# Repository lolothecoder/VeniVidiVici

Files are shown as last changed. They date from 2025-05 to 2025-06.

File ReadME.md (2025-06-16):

# VeniVidiVici
### Loïc Finette, Oussama Jaffal, Adnane El Haouat
Repository for the Robotics Competition Team “VeniVidiVici”

---

## Overview

This workspace bundles everything needed to get our robot up and running in the competition:

- **ROSArduinoBridge**  
  Low-level firmware running on the Arduino, handling sensor I/O and motor control.

- **diffdrive_arduino**  
  Differential-drive hardware interface for Arduino.

- **rplidar_ros2**  
  Driver for the A1M8 RPLidar unit, published as a ROS 2 node.

- **veni_vidi_vici_bot_one**  
  Template repo integrating SLAM and Nav2—your quick start to mapping and navigation.

---

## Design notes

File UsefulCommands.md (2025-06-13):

run docker image:
docker run -dit --name ros_vvv \
  --privileged \
  --network host \
  --ipc host \
  --device /dev/video0:/dev/video0 \
  --device /dev/ttyUSB0:/dev/ttyUSB0 \
  -e DISPLAY=$DISPLAY \
  -v /tmp/.X11-unix:/tmp/.X11-unix:rw \
  -v /home/triplev/.Xauthority:/root/.Xauthority:ro \
  -v /home/triplev/Documents/VeniVidiVici/veni_vidi_vici_bot_one:/root/ros_ws/src/veni_vidi_vici_bot_one \
  -v /home/triplev/Documents/VeniVidiVici/rplidar_ros2:/root/ros_ws/src/rplidar_ros2 \
  -v /home/triplev/Documents/VeniVidiVici/diffdrive_arduino:/root/ros_ws/src/diffdrive_arduino \
  -v /home/triplev/Documents/VeniVidiVici/ball_tracker:/root/ros_ws/src/ball_tracker \
  -v /dev/bus/usb:/dev/bus/usb \
  leshrimpkiller/vvv:latest bash

execute terminal in same container
docker exec -it ros_vvv bash

build docker image:
docker build -t leshrimpkiller/vvv .

source:
source install/setup.bash

launch robot:
alaunch
ros2 launch veni_vidi_vici_bot_one launch_robot.launch.py 

ros2 launch veni_vidi_vici_bot_one VVV_launch_robot.launch.py activate_loc:=true activate_nav:=true activate_sm:=true

list container:
docker container ls

run teleop:
ateleop
ros2 run teleop_twist_keyboard teleop_twist_keyboard --ros-args -r /cmd_vel:=/diff_cont/cmd_vel_unstamped

Put code on Arduino
acompile ROSArduinoBridge/ && aupload ROSArduinoBridge/

Controlling motors through pyserial
pyserial-miniterm -e /dev/ttyACM0 57600
type: f for battery

create new bash
anewbash
sudo docker exec -it $(sudo docker ps -aqf "ancestor=leshrimpkiller/vvv") bash

Launch lidar
ros2 run rplidar_ros rplidar_composition --ros-args -p serial_port:=/dev/ttyUSB0 -p frame_id:=laser_frame -p angle_compensate:=true -p scan_mode:=Standard

ros2 launch rplidar_ros rplidar.launch.py frame_id:=laser_frame

Run Rviz docker:

ssh -X triplev@172.21.68.240

xhost +local:root  # Allow local root user to access X server

export XAUTHORITY=/home/triplev/.Xauthority

sudo docker run --rm -it --privileged --net=host \
  -e DISPLAY=$DISPLAY \
  -v /tmp/.X11-unix:/tmp/.X11-unix:rw \
  -v /home/triplev/.Xauthority:/root/.Xauthority:ro \
  -v /dev/bus/usb:/dev/bus/usb \
  leshrimpkiller/vvv:latest bash

echo $DISPLAY       
echo $XAUTHORITY 

rviz2

ros2 launch slam_toolbox online_async_launch.py params_file:=./src/veni_vidi_vici_bot_one/config/mapper_params_online_async.yaml use_sim_time:=false

ros2 launch veni_vidi_vici_bot_one VVV_launch_robot.launch.py activate_sm:=true use_ros2_control:=true activate_nav:=true activate_loc:=true

source /opt/ros/humble/setup.bash
source ~/ros_ws/install/setup.bash
export ROS_DOMAIN_ID=5

ros2 launch veni_vidi_vici_bot_one VVV_launch_robot.launch.py activate_nav:=true activate_loc:=true activate_sm:=true use_ros2_control:=true 

ros2 topic pub /start_signal std_msgs/msg/Empty '{}'

 bash -x src/veni_vidi_vici_bot_one/veni_vidi_vici_bot_one/go_bot.sh

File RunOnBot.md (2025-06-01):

Plug in therobot using either an alim or battery

With alim use adapter

With battery take out the adapter and plug in the white JST connector (RED N RED PLEASE). Then plug in the power. Press the reset button on the powerboard. Flip the switch on. If it doesn't work play around with the switch (On and off). MAKE SURE the battery has more than 10.5 V left in it.

Pull new docker image:
docker pull leshrimpkiller/vvv

login info:
ssh: lolon@172.21.69.243
pswd: milotamario64

If you want to use rviz2 or any GUI apps:
ssh -X lolon@172.21.69.243

xhost +local:root  # Allow local root user to access X server

export XAUTHORITY=/home/lolon/.Xauthority

sudo docker run --rm -it --privileged --net=host \
  -e DISPLAY=$DISPLAY \
  -v /tmp/.X11-unix:/tmp/.X11-unix:rw \
  -v /home/lolon/.Xauthority:/root/.Xauthority:ro \
  -v /dev/bus/usb:/dev/bus/usb \
  leshrimpkiller/vvv:latest bash

echo $DISPLAY       
echo $XAUTHORITY 

rviz2 

!!MAKE SURE YOU RUN THE LAUNCH FILE THAT LAUNCHES GUI APPS LAST!!

Open up a bunch of terminals with either 
- anewbash
- docker exec -it <CONTAINER> bash

Source terminal

FIRST run the robot launch file with : 
ros2 launch veni_vidi_vici_bot_one launch_robot.launch.py

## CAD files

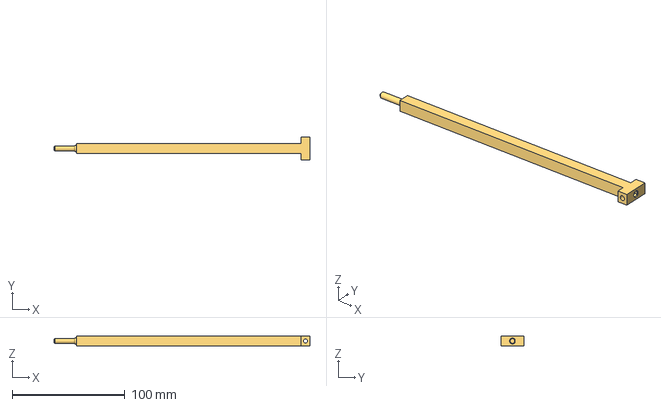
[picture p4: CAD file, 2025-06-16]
CAD/grabber_axe v6 v7.step
227.0 x 20.7 x 8.70 mm

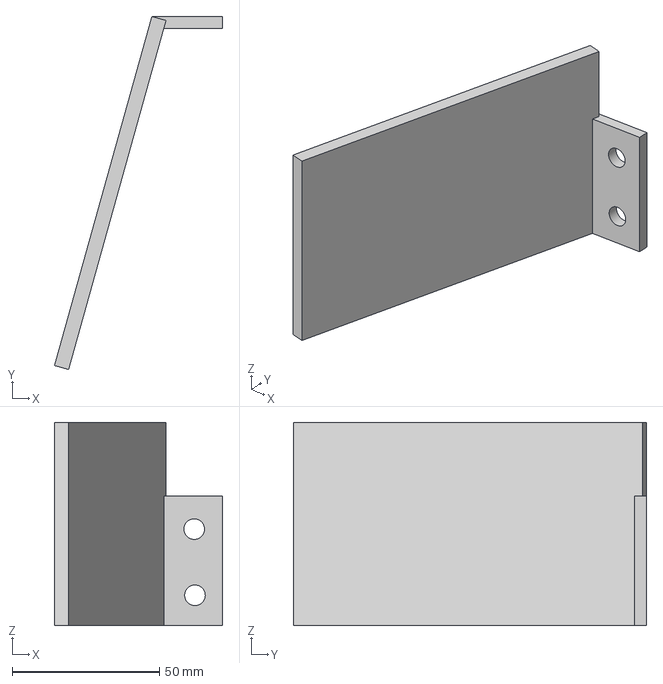
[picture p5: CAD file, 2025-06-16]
CAD/Protege_roue_2 v2.step
57.1 x 119.8 x 69.0 mm

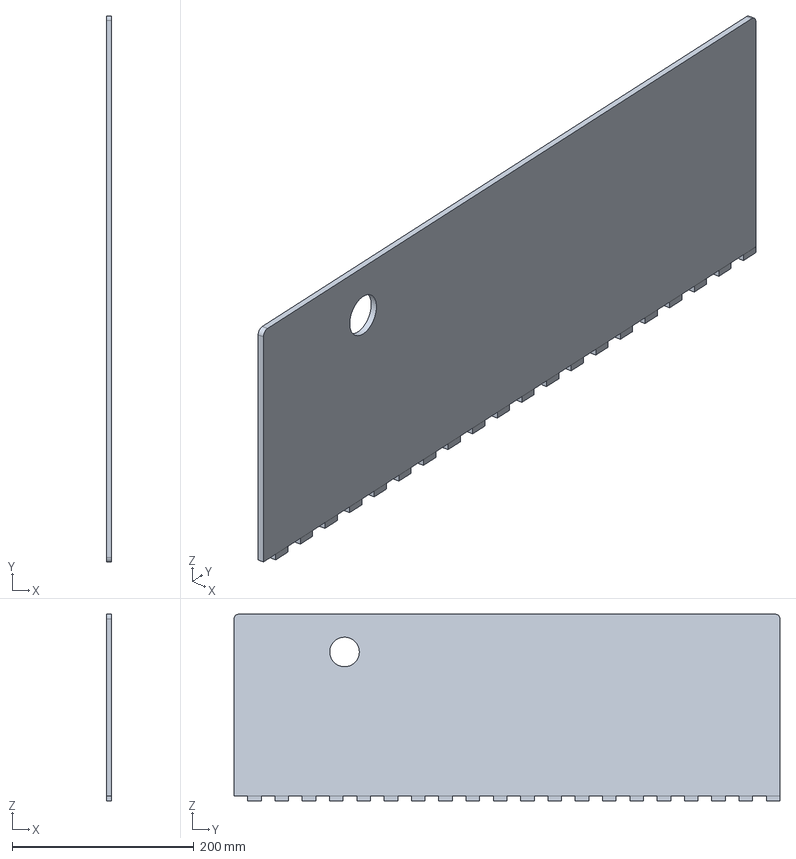
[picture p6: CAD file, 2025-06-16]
CAD/chassis_final_base_lateralll v7.step
5.03 x 600.0 x 205.0 mm

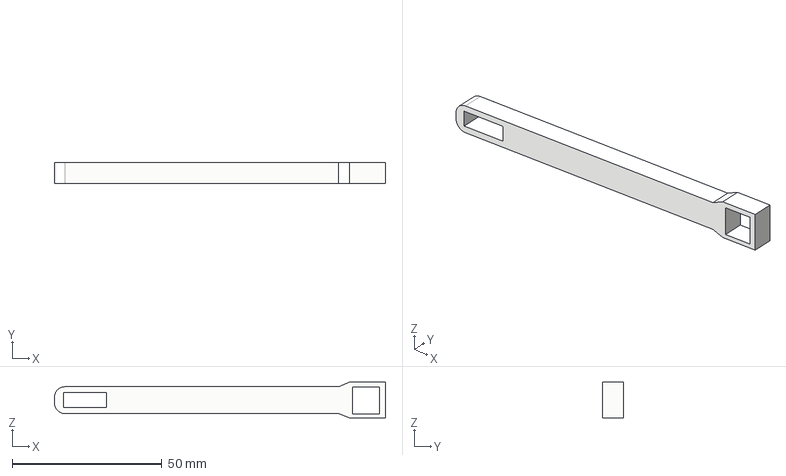
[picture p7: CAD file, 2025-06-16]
CAD/Grab_piece1 v1.step
110.6 x 7.00 x 12.0 mm

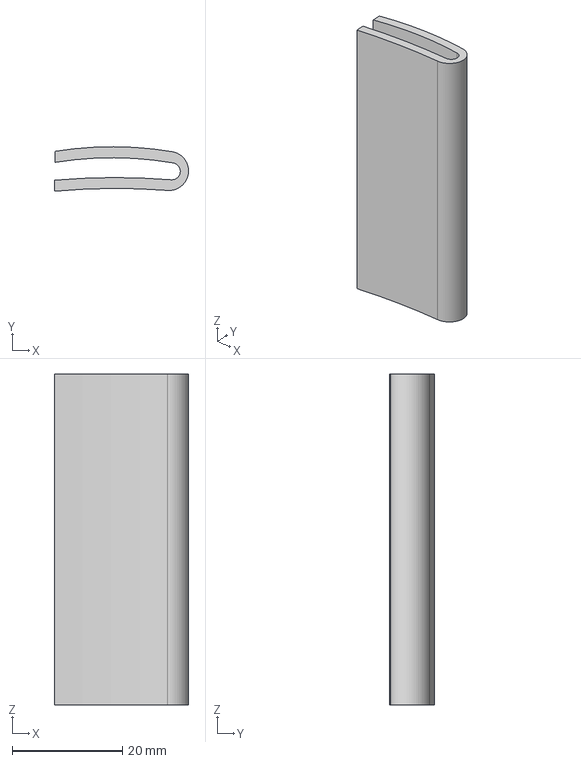
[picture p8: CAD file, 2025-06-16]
CAD/protege_rampe v2.step
24.3 x 8.07 x 60.0 mm

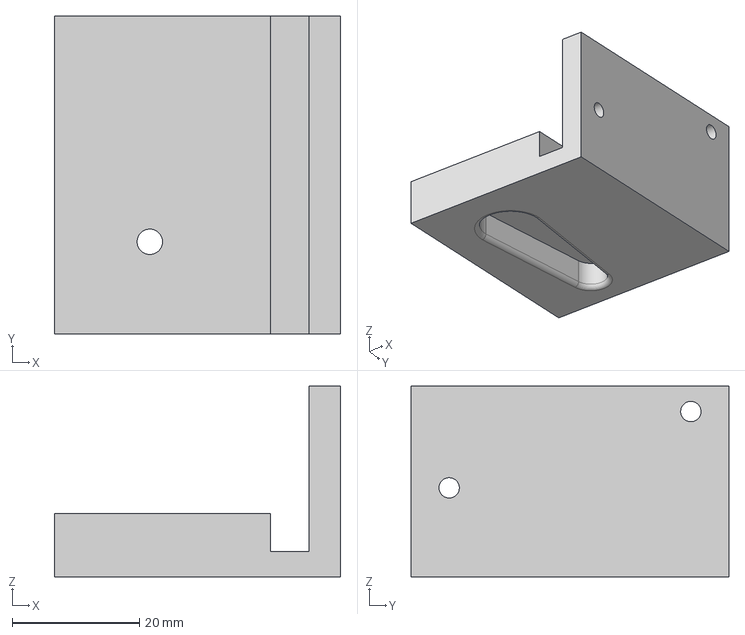
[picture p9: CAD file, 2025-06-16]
CAD/HolderSupport.step
45.0 x 50.0 x 30.0 mm

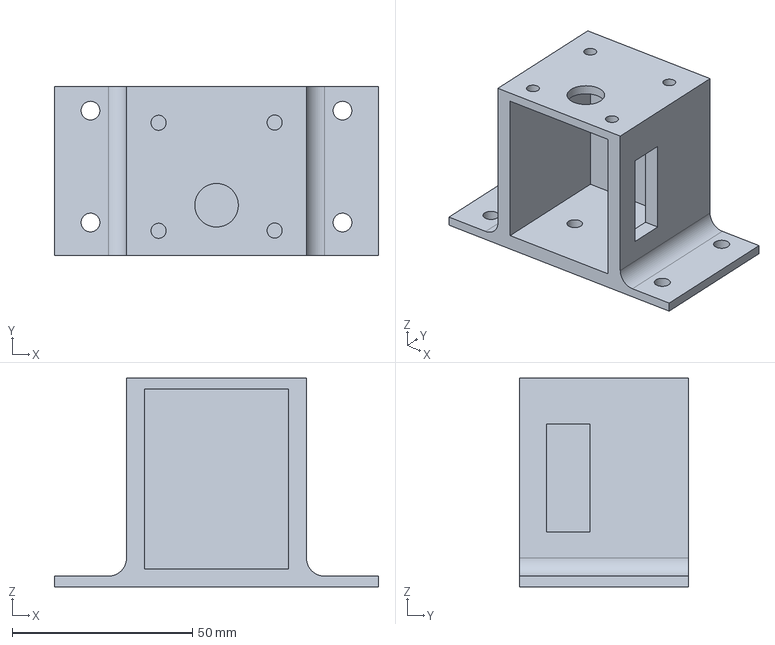
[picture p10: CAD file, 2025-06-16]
CAD/Prototype_final_support_roues v7.step
90.0 x 47.0 x 58.0 mm

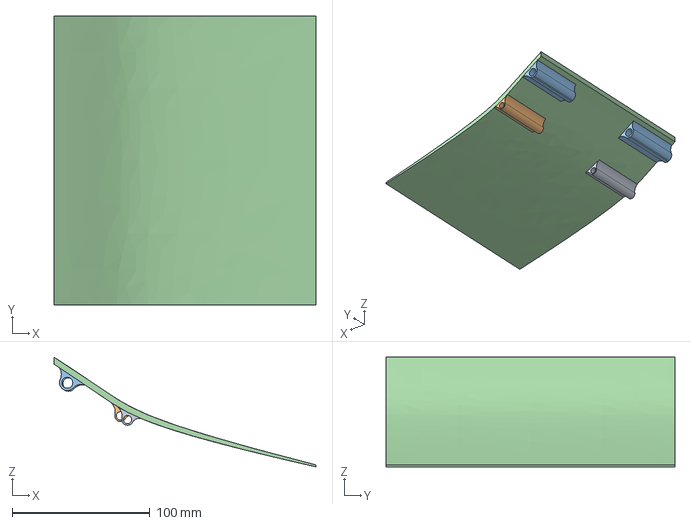
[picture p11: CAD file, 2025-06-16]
CAD/Prototype_final_rampe_du_devant v10.step
190.3 x 210.0 x 79.7 mm

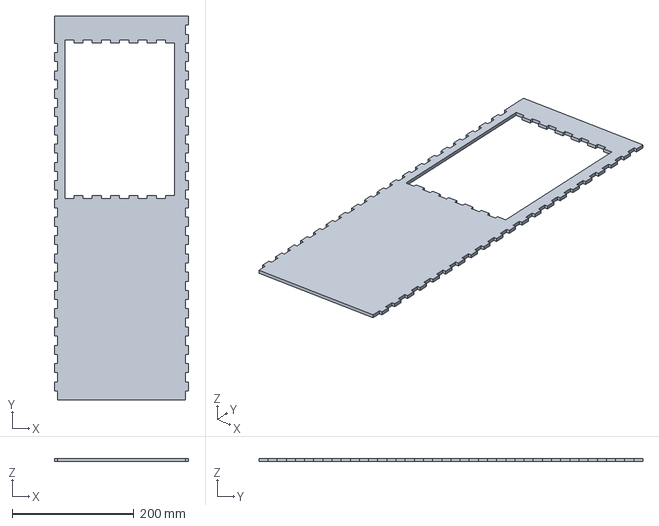
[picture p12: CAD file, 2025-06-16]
CAD/Esquisse_Prototype_Final_Base_du_haut v2.step
220.0 x 629.7 x 5.00 mm

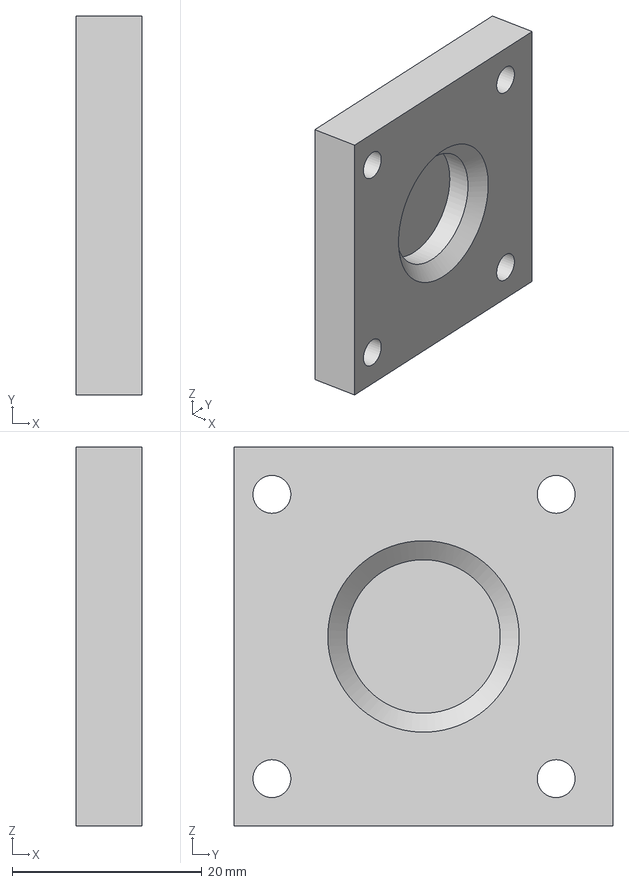
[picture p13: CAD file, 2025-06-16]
CAD/Bearing_Holder.3mf
7.00 x 40.0 x 40.0 mm

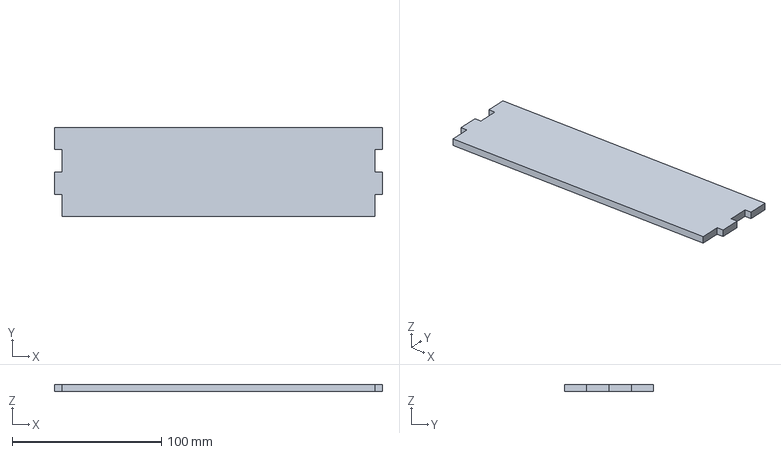
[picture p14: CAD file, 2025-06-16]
CAD/Prototype_finale_pièce_bouton v4.step
220.0 x 60.0 x 5.00 mm

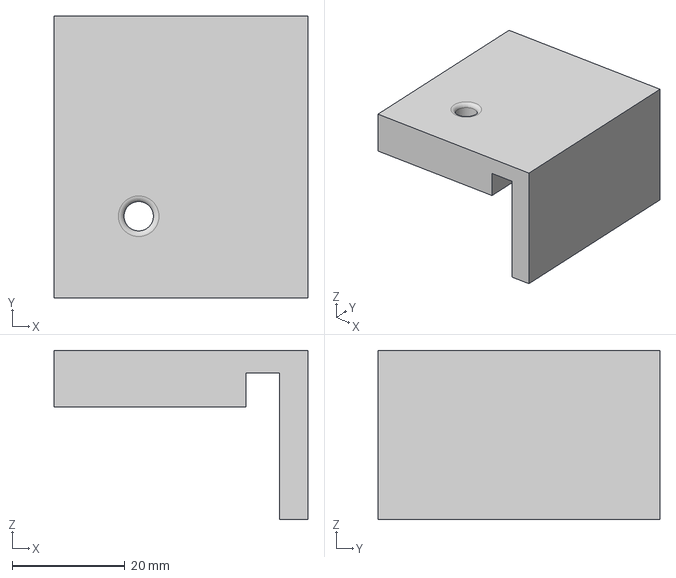
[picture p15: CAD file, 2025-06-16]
CAD/HolderSupportBEARING v3.step
45.0 x 50.0 x 30.0 mm

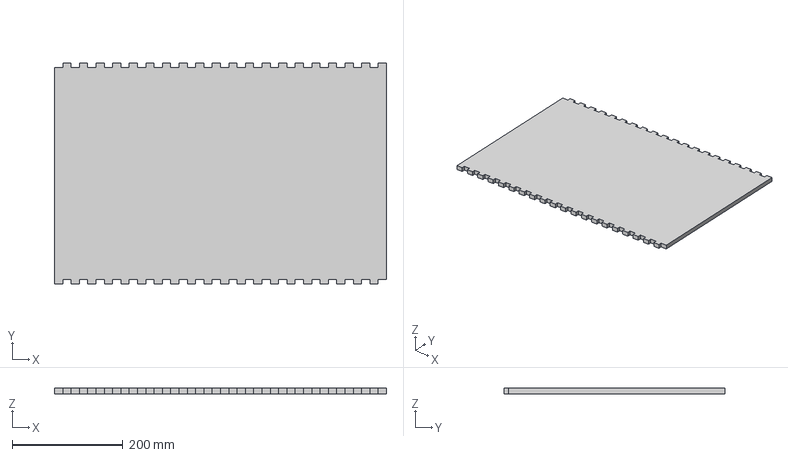
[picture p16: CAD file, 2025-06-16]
CAD/Chassis robot v1.step
600.0 x 400.0 x 10.0 mm

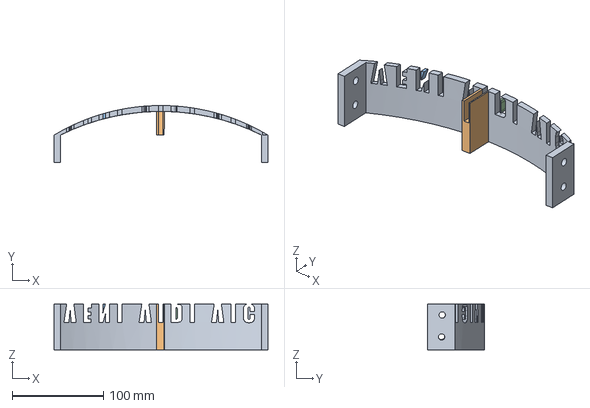
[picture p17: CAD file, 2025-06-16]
CAD/VENI_VIDI_VICI v2.step
235.0 x 62.5 x 50.0 mm

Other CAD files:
CAD/Grab_piece2 v7.step
CAD/Prototype_finale_bearing_support v1.step
CAD/Bearing_holder v1.step

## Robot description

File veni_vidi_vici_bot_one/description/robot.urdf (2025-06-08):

<?xml version="1.0" ?>
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
<robot name="robot">
  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
  <link name="base_link">

    </link>
  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
  <joint name="base_footprint_joint" type="fixed">
    <parent link="base_link"/>
    <child link="base_footprint"/>
    <origin rpy="0 0 0" xyz="0 0 0"/>
  </joint>
  <link name="base_footprint">
    </link>
  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
  <joint name="chassis_joint" type="fixed">
    <parent link="base_link"/>
    <child link="chassis"/>
    <origin xyz="-0.43 0 -0.01"/>
  </joint>
  <link name="chassis">
    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
    <inertial>
      <origin rpy="0 0 0" xyz="0.315 0 0.1025"/>
      <mass value="0.5"/>
      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
    </inertial>
  </link>
  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
  <joint name="left_wheel_joint" type="continuous">
    <parent link="base_link"/>
    <child link="left_wheel"/>
    <origin rpy="-1.5707963267948966 0 0" xyz="0 0.2155 0"/>
    <axis xyz="0 0 1"/>
  </joint>
  <link name="left_wheel">
    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
    <inertial>
      <origin rpy="0 0 0" xyz="0 0 0"/>
      <mass value="0.16"/>
      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
    </inertial>
  </link>
  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
  <joint name="right_wheel_joint" type="continuous">
    <parent link="base_link"/>
    <child link="right_wheel"/>
    <origin rpy="1.5707963267948966 0 0" xyz="0 -0.2155 0"/>
    <axis xyz="0 0 -1"/>
  </joint>
  <link name="right_wheel">
    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
    <inertial>
      <origin rpy="0 0 0" xyz="0 0 0"/>
      <mass value="0.16"/>
      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
    </inertial>
  </link>
  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
  <joint name="right_caster_wheel_joint" type="fixed">
    <parent link="chassis"/>
    <child link="right_caster_wheel"/>
    <origin xyz="0.025 -0.168 -0.024999999999999994"/>
  </joint>
  <link name="right_caster_wheel">
    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
    <inertial>
      <origin rpy="0 0 0" xyz="0 0 0"/>
      <mass value="0.01"/>
      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
    </inertial>
  </link>
  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
  <joint name="left_caster_wheel_joint" type="fixed">
    <parent link="chassis"/>
    <child link="left_caster_wheel"/>
    <origin xyz="0.025 0.168 -0.024999999999999994"/>
  </joint>
  <link name="left_caster_wheel">
    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
    <inertial>
      <origin rpy="0 0 0" xyz="0 0 0"/>
      <mass value="0.01"/>
      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
    </inertial>
  </link>
  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
  <joint name="door_joint" type="continuous">
    <origin rpy="1.57 0 0" xyz="-0.20 0.13 0.13"/>
    <parent link="base_link"/>
    <child link="door_servo_frame"/>
  </joint>
  <link name="door_servo_frame">
    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
    <inertial>
      <mass value="0.04021467988426049"/>
      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
    </inertial>
  </link>
  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
  <joint name="ramp_joint" type="continuous">
    <origin rpy="1.57 0 0" xyz="-0.40 0.13 0.13"/>
    <parent link="base_link"/>
    <child link="ramp_servo_frame"/>
  </joint>
  <link name="ramp_servo_frame">
    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
    <inertial>
      <mass value="0.04021467988426049"/>
      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
    </inertial>
  </link>
  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
  <joint name="collector_joint" type="continuous">
    <origin rpy="1.57 0 0" xyz="0.20 0.13 0.13"/>
    <parent link="base_link"/>
    <child link="collector_servo_frame"/>
  </joint>
  <link name="collector_servo_frame">
    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
    <inertial>
      <mass value="0.04021467988426049"/>
      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
    </inertial>
  </link>
  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
  <ros2_control name="RealRobot" type="system">
    <hardware>
      <plugin>diffdrive_arduino/DiffDriveArduinoHardware</plugin>
      <param name="left_wheel_name">left_wheel_joint</param>
      <param name="right_wheel_name">right_wheel_joint</param>
      <param name="door_servo_name">door_joint</param>
      <param name="ramp_servo_name">ramp_joint</param>
      <param name="collector_servo_name">collector_joint</param>
      <param name="loop_rate">30</param>
      <param name="device">/dev/ttyACM0</param>
      <param name="baud_rate">57600</param>
      <param name="timeout_ms">1000</param>
      <param name="enc_counts_per_rev">3436</param>
      <param name="pid_p">20</param>
      <param name="pid_d">12</param>
      <param name="pid_i">0</param>
      <param name="pid_o">50</param>
    </hardware>
    <joint name="left_wheel_joint">
      <command_interface name="velocity">
        <param name="min">-20</param>
        <param name="max">20</param>
      </command_interface>
      <state_interface name="position"/>
      <state_interface name="velocity"/>
    </joint>
    <joint name="right_wheel_joint">
      <command_interface name="velocity">
        <param name="min">-20</param>
        <param name="max">20</param>
      </command_interface>
      <state_interface name="position"/>
      <state_interface name="velocity"/>
    </joint>
    <joint name="door_joint">
      <command_interface name="velocity">
        <param name="min">-5</param>
        <param name="max">5</param>
      </command_interface>
      <state_interface name="position"/>
      <state_interface name="velocity"/>
    </joint>
    <joint name="ramp_joint">
      <command_interface name="velocity">
        <param name="min">-5</param>
        <param name="max">5</param>
      </command_interface>
      <state_interface name="position"/>
      <state_interface name="velocity"/>
    </joint>
    <joint name="collector_joint">
      <command_interface name="velocity">
        <param name="min">-5</param>
        <param name="max">5</param>
      </command_interface>
      <state_interface name="position"/>
      <state_interface name="velocity"/>
    </joint>
  </ros2_control>
  <joint name="laser_joint" type="fixed">
    <parent link="chassis"/>
    <child link="laser_frame"/>
    <origin rpy="0 0 0" xyz="0.445 0.04 0.28"/>
  </joint>
  <link name="laser_frame">
    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
    <inertial>
      <origin rpy="0 0 0" xyz="0 0 0"/>
      <mass value="0.1"/>
      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
    </inertial>
  </link>
  <joint name="camera_joint" type="fixed">
    <parent link="chassis"/>
    <child link="camera_link"/>
    <origin rpy="0 0.436332 0" xyz="0.615 0 0.24"/>
  </joint>
  <link name="camera_link">
    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
  </link>
  <joint name="camera_optical_joint" type="fixed">
    <parent link="camera_link"/>
    <child link="camera_link_optical"/>
    <origin rpy="-1.5707963267948966 0 -1.5707963267948966" xyz="0 0 0"/>
  </joint>
  <link name="camera_link_optical"/>
</robot>

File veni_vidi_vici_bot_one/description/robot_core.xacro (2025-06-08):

<?xml version="1.0"?>
<robot xmlns:xacro="http://www.ros.org/wiki/xacro" >

    <xacro:include filename="inertial_macros.xacro"/>


    <xacro:property name="chassis_length" value="0.63"/>
    <xacro:property name="chassis_width" value="0.35"/>
    <xacro:property name="chassis_height" value="0.205"/>
    <xacro:property name="chassis_mass" value="4.75"/>
    <xacro:property name="wheel_radius" value="0.06"/>
    <xacro:property name="wheel_thickness" value="0.061"/>
    <xacro:property name="wheel_mass" value="0.160"/>
    <xacro:property name="wheel_offset_x" value="0.43"/>
    <xacro:property name="wheel_offset_y" value="0.185"/>
    <xacro:property name="wheel_offset_z" value="0.01"/>
    <xacro:property name="caster_wheel_radius" value="0.025"/>
    <xacro:property name="caster_wheel_mass" value="0.01"/>
    <xacro:property name="caster_wheel_offset_x" value="0.025"/>
    <xacro:property name="caster_wheel_offset_y" value="0.168"/>
    <xacro:property name="caster_wheel_offset_z" value="${wheel_offset_z - wheel_radius + caster_wheel_radius}"/>

    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

    <link name="base_link">

    </link>

    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

    <joint name="base_footprint_joint" type="fixed">
        <parent link="base_link"/>
        <child link="base_footprint"/>
        <origin xyz="0 0 0" rpy="0 0 0"/>
    </joint>

    <link name="base_footprint">
    </link>


    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

    <joint name="chassis_joint" type="fixed">
        <parent link="base_link"/>
        <child link="chassis"/>
        <origin xyz="${-wheel_offset_x} 0 ${-wheel_offset_z}"/>
    </joint>

    <link name="chassis">
        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
        <xacro:inertial_box mass="0.5" x="${chassis_length}" y="${chassis_width}" z="${chassis_height}">
            <origin xyz="${chassis_length/2} 0 ${chassis_height/2}" rpy="0 0 0"/>
        </xacro:inertial_box>
    </link>

    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

    <joint name="left_wheel_joint" type="continuous">
        <parent link="base_link"/>
        <child link="left_wheel"/>
        <origin xyz="0 ${wheel_offset_y + wheel_thickness/2} 0" rpy="-${pi/2} 0 0" />
        <axis xyz="0 0 1"/>
    </joint>

    <link name="left_wheel">
        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
        <xacro:inertial_cylinder mass="${wheel_mass}" length="${wheel_thickness}" radius="${wheel_radius}">
            <origin xyz="0 0 0" rpy="0 0 0"/>
        </xacro:inertial_cylinder>
    </link>

    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

    <joint name="right_wheel_joint" type="continuous">
        <parent link="base_link"/>
        <child link="right_wheel"/>
        <origin xyz="0 ${-(wheel_offset_y + wheel_thickness/2)} 0" rpy="${pi/2} 0 0" />
        <axis xyz="0 0 -1"/>
    </joint>

    <link name="right_wheel">
        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
        <xacro:inertial_cylinder mass="${wheel_mass}" length="${wheel_thickness}" radius="${wheel_radius}">
            <origin xyz="0 0 0" rpy="0 0 0"/>
        </xacro:inertial_cylinder>
    </link>

    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

    <joint name="right_caster_wheel_joint" type="fixed">
        <parent link="chassis"/>
        <child link="right_caster_wheel"/>
        <origin xyz="${caster_wheel_offset_x} ${-caster_wheel_offset_y} ${caster_wheel_offset_z}"/>
    </joint>


    <link name="right_caster_wheel">
        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
        <xacro:inertial_sphere mass="${caster_wheel_mass}" radius="${caster_wheel_radius}">
            <origin xyz="0 0 0" rpy="0 0 0"/>
        </xacro:inertial_sphere>
    </link>


    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

    <joint name="left_caster_wheel_joint" type="fixed">
        <parent link="chassis"/>
        <child link="left_caster_wheel"/>
        <origin xyz="${caster_wheel_offset_x} ${caster_wheel_offset_y} ${caster_wheel_offset_z}"/>
    </joint>


    <link name="left_caster_wheel">
        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
        <xacro:inertial_sphere mass="${caster_wheel_mass}" radius="${caster_wheel_radius}">
            <origin xyz="0 0 0" rpy="0 0 0"/>
        </xacro:inertial_sphere>
    </link>

    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

    <joint name="door_joint" type="continuous">
        <origin xyz="-0.20 0.13 0.13" rpy="1.57 0 0"/>
        <parent link="base_link"/>
        <child link="door_servo_frame"/>
    </joint>

    <link name="door_servo_frame">
        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
        <inertial>
            <mass value="0.04021467988426049"/>
            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
        </inertial>
    </link>

    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

    <joint name="ramp_joint" type="continuous">
        <origin xyz="-0.40 0.13 0.13" rpy="1.57 0 0"/>
        <parent link="base_link"/>
        <child link="ramp_servo_frame"/>
    </joint>

    <link name="ramp_servo_frame">
        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
        <inertial>
            <mass value="0.04021467988426049"/>
            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
        </inertial>
    </link>

    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

    <joint name="collector_joint" type="continuous">
        <origin xyz="0.20 0.13 0.13" rpy="1.57 0 0"/>
        <parent link="base_link"/>
        <child link="collector_servo_frame"/>
    </joint>

    <link name="collector_servo_frame">
        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
        <inertial>
            <mass value="0.04021467988426049"/>
            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
        </inertial>
    </link>

    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

    <joint name="imu_joint" type="fixed">
        <origin xyz="-0.16 0.05 0.20" rpy="0 0 0"/>
        <parent link="base_link"/>
        <child link="imu_link"/>
    </joint>

    <link name="imu_link">
        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
        <inertial>
            <mass value="0.04021467988426049"/>
            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
        </inertial>
    </link>

</robot>

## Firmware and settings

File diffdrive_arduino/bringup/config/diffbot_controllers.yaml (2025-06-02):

controller_manager:
  ros__parameters:
    update_rate: 10  # Hz

    joint_state_broadcaster:
      type: joint_state_broadcaster/JointStateBroadcaster

    diffbot_base_controller:
      type: diff_drive_controller/DiffDriveController

diffbot_base_controller:
  ros__parameters:
    left_wheel_names: ["left_wheel_joint"]
    right_wheel_names: ["right_wheel_joint"]

    wheel_separation: 0.44
    #wheels_per_side: 1  # actually 2, but both are controlled by 1 signal
    wheel_radius: 0.06

    wheel_separation_multiplier: 1.0
    left_wheel_radius_multiplier: 1.0
    right_wheel_radius_multiplier: 1.0

    publish_rate: 50.0
    odom_frame_id: odom
    base_frame_id: base_link
    pose_covariance_diagonal : [0.001, 0.001, 0.001, 0.001, 0.001, 0.01]
    twist_covariance_diagonal: [0.001, 0.001, 0.001, 0.001, 0.001, 0.01]

    open_loop: true
    enable_odom_tf: true

    cmd_vel_timeout: 0.5
    #publish_limited_velocity: true
    use_stamped_vel: false
    #velocity_rolling_window_size: 10

    # Velocity and acceleration limits
    # Whenever a min_* is unspecified, default to -max_*
    linear.x.has_velocity_limits: true
    linear.x.has_acceleration_limits: true
    linear.x.has_jerk_limits: false
    linear.x.max_velocity: 1.0
    linear.x.min_velocity: -1.0
    linear.x.max_acceleration: 1.0
    linear.x.max_jerk: 0.0
    linear.x.min_jerk: 0.0

    angular.z.has_velocity_limits: true
    angular.z.has_acceleration_limits: true
    angular.z.has_jerk_limits: false
    angular.z.max_velocity: 1.0
    angular.z.min_velocity: -1.0
    angular.z.max_acceleration: 1.0
    angular.z.min_acceleration: -1.0
    angular.z.max_jerk: 0.0
    angular.z.min_jerk: 0.0

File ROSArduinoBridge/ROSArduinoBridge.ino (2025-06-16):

#include <Servo.h>
#include <Adafruit_MPU6050.h>
#include <Adafruit_Sensor.h>
#include <Wire.h>
/*********************************************************************
 *  ROSArduinoBridge
 *  ...
 *********************************************************************/

#define USE_BASE      // Enable the base controller code

#ifdef USE_BASE
   #define ARDUINO_ENC_COUNTER
   #define ESCON_MAXON
   #define GRABBER
   #define BATTERY
   #define CUSTOM_SERVOS
   //Adafruit_MPU6050 mpu;
   #define SPIN_BACK  2000
#endif

#undef USE_SERVOS     // Disable use of PWM servos

#define BAUDRATE       57600
#define MAX_PWM        255

#if defined(ARDUINO) && ARDUINO >= 100
  #include "Arduino.h"
#else
  #include "WProgram.h"
#endif

#include "commands.h"
#include "sensors.h"
#include "sensors_updated.h"

#ifdef USE_SERVOS
  #include <Servo.h>
  #include "servos.h"
#endif

#ifdef USE_BASE
  #include <Servo.h>
  #include "custom_servos.h"
  #include "motor_driver.h"
  #include "encoder_driver.h"
  #include "diff_controller.h"

  #define PID_RATE           30     // Hz
  const int PID_INTERVAL = 1000 / PID_RATE;
  unsigned long nextPID = PID_INTERVAL;

  #define AUTO_STOP_INTERVAL 2000
  long lastMotorCommand   = AUTO_STOP_INTERVAL;
  long lastGrabberCommand = AUTO_STOP_INTERVAL;
  long lastServoCommand   = AUTO_STOP_INTERVAL;
#endif

/* Globals for serial parsing */
int arg = 0;
int index = 0;
char chr;
char cmd;
char argv1[16];
char argv2[16];
long arg1;
long arg2;
bool collector_activated = false;
float left_speed = 0;
float right_speed = 0;
float voltage_battery = 0;
float a_x = 0; float a_y = 0; float a_z = 0;
float g_x = 0; float g_y = 0; float g_z = 0;

const int encoderPinA = A0;
unsigned long switchCount = 0;
bool lastA = LOW;
unsigned long lastReport = 0;
bool grabber = false;
bool stuck = false;
unsigned long stuckTime = 0;
unsigned long checkEncoder = 0;
bool set_time = false;

void battery_level(){
        float value = analogRead(BATTERY_PIN);
        float pin_volt = value / MAX_ARD_VAL * MAX_PIN_VAL;
        float true_bat_volt = pin_volt * (R7 + R8) / R8;
        //Serial.println("Battery Voltage:");
        //Serial.println(true_bat_volt);
        voltage_battery = true_bat_volt;  // Store for later use
    }

/* Encoder/stuck‐detection specifics */
#ifdef USE_BASE
  // We’ll poll A0 as a digital input for the grabber encoder
  #define ENCODER_A_PIN         A0

  volatile unsigned long pulseCount         = 0;    // counts BOTH edges on A0
  uint8_t                lastA0state        = LOW;

  const unsigned long    CHECK_WINDOW       = 500UL;   // 500 ms window
  const unsigned int     MIN_PULSES         = 30;      // ≥30 edges per window ⇒ “turning”
  const unsigned long    REVERSE_DURATION   = 2000UL;  // 2 seconds to reverse when stuck

  unsigned long          lastWindowTime       = 0;
  unsigned long          lastWindowPulseCount = 0;
  unsigned long          reverseUntil         = 0;     // millis until which we reverse
  bool                   currentlyReversing   = false;

  // Default grabber speed (PWM). Adjust as needed.
  const int              DEFAULT_GRABBER_SPEED = 100;
#endif

/* Forward declarations */
void resetCommand();
int runCommand();
void setGrabberSpeed(int spd);

/* Clear the current command parameters */
void resetCommand() {
  cmd = NULL;
  memset(argv1, 0, sizeof(argv1));
  memset(argv2, 0, sizeof(argv2));
  arg1 = 0;
  arg2 = 0;
  arg = 0;
  index = 0;
}

/* Run a command. Commands are defined in commands.h */
int runCommand() {
  int i = 0;
  char *p = argv1;
  char *str;
  int pid_args[4];
  arg1 = atoi(argv1);
  arg2 = atoi(argv2);

  switch(cmd) {

#ifdef USE_BASE
    case READ_ENCODERS:
      Serial.print(readEncoder(LEFT));
      Serial.print(" ");
      Serial.println(readEncoder(RIGHT));
      break;
    case MOTOR_RAW_PWM:
      lastMotorCommand = millis();
      resetPID();
      moving = 0; // temporarily disable PID
      setMotorSpeeds(arg1, arg2);
      left_speed  = arg1;
      right_speed = arg2;
      //if (stuck){
      //  setGrabberSpeed(80);
      //}
      Serial.println("OK");
      break;
    case GRABBER_RAW_PWM:
      lastGrabberCommand = millis();
      if(arg1!= 0){
        collector_activated = true;
        checkEncoder = millis();
      }
      if(stuck){
        if(millis() - stuckTime > SPIN_BACK){
          stuck = false;
          collector_activated = false;
          //Serial.println("UNSTUCK");
        }
        setGrabberSpeed(-arg1);
      }
      else{
        setGrabberSpeed(arg1);
      }

      if(arg1 == 0) {
        collector_activated = false;
        currentlyReversing  = false;
        reverseUntil        = 0;
        grabber = false;
        stuck = false;
        set_time = false;
      }
      Serial.println("OK");
      break;
    case BATTERY_LEVEL:
      battery_level();
      Serial.print("Battery Voltage: ");
      Serial.println(voltage_battery);
      Serial.println("OK");
      break;
    case ACTIVATE_SERVO:
      lastServoCommand = millis();
      setServo(arg1, arg2);
      Serial.println("OK");
      break;
    case GET_INFO:
      Serial.print(left_speed);
      Serial.print(" ");
      Serial.println(right_speed);
      break;
    case GET_IMU:
      //Serial.print(a_x);
      //Serial.print(" ");
      //Serial.print(a_y);
      //Serial.print(" ");
      //Serial.print(a_z);
      //Serial.print(" ");
      //Serial.print(g_x);
      //Serial.print(" ");
      //Serial.print(g_y);
      //Serial.print(" ");
      //Serial.println(g_z);
      break;
#endif

    default:
      Serial.println("Invalid Command");
      break;
  }
  return 0;
}

/* Setup function—runs once at startup. */
void setup() {
  Serial.begin(BAUDRATE);
  //Wire.begin();                    //  ← Initialize I²C bus
  //if (! mpu.begin()) {             //  ← Probe the sensor
  //  Serial.println("Failed to find MPU6050!");
  //  while (1) delay(10);
  //}
  pinMode(LEFT_ENABLE, OUTPUT);
  pinMode(LEFT_PWM, OUTPUT);
  pinMode(LEFT_DIRECTION, OUTPUT);

  pinMode(RIGHT_ENABLE, OUTPUT);
  pinMode(RIGHT_PWM, OUTPUT);
  pinMode(RIGHT_DIRECTION, OUTPUT);

  pinMode(GRABBER_DIRECTION, OUTPUT);
  pinMode(GRABBER_PWM, OUTPUT);

  pinMode(BATTERY_PIN, INPUT);
  pinMode(encoderPinA, INPUT_PULLUP);
  lastA = digitalRead(encoderPinA);
  //mpu.setAccelerometerRange(MPU6050_RANGE_4_G);
  //mpu.setGyroRange(MPU6050_RANGE_250_DEG);
  //mpu.setFilterBandwidth(MPU6050_BAND_21_HZ);
#ifdef USE_BASE
  #ifdef ARDUINO_ENC_COUNTER
    // Left encoder pins (directly on Arduino pins)
    DDRD &= ~(1 << LEFT_ENC_PIN_A);
    DDRD &= ~(1 << LEFT_ENC_PIN_B);
    PORTD |= (1 << LEFT_ENC_PIN_A);
    PORTD |= (1 << LEFT_ENC_PIN_B);

    // Right encoder pins
    DDRC &= ~(1 << RIGHT_ENC_PIN_A);
    DDRC &= ~(1 << RIGHT_ENC_PIN_B);
    PORTC |= (1 << RIGHT_ENC_PIN_A);
    PORTC |= (1 << RIGHT_ENC_PIN_B);

    // Enable pin‐change interrupts for left and right encoders
    PCMSK2 |= (1 << LEFT_ENC_PIN_A) | (1 << LEFT_ENC_PIN_B);
    PCMSK1 |= (1 << RIGHT_ENC_PIN_A) | (1 << RIGHT_ENC_PIN_B);
    PCICR  |= (1 << PCIE1) | (1 << PCIE2);
  #endif

  initMotorController();
  initServos();
  resetPID();

  // — Grabber‐encoder polling setup —
  pinMode(ENCODER_A_PIN, INPUT_PULLUP);
  lastA0state = digitalRead(ENCODER_A_PIN);

  lastWindowTime       = millis();
  lastWindowPulseCount = 0;
  reverseUntil         = 0;
  currentlyReversing   = false;
#endif

#ifdef USE_SERVOS
  for (int i = 0; i < N_SERVOS; i++) {
    servos[i].initServo(
      servoPins[i],
      stepDelay[i],
      servoInitPosition[i]
    );
  }
  delay(100);
#endif
}

/* Main loop: read serial, run commands, PID, auto‐stop, and stuck check */
void loop() {
  //sensors_event_t a, g, temp;
  //mpu.getEvent(&a, &g, &temp);
  // 1) Handle incoming serial commands
  while (Serial.available() > 0) {
    chr = Serial.read();
    if (chr == 13) {               // CR terminates command
      if (arg == 1) argv1[index] = NULL;
      else if (arg == 2) argv2[index] = NULL;
      runCommand();
      resetCommand();
    }
    else if (chr == ' ') {         // space delimits
      if (arg == 0) arg = 1;
      else if (arg == 1) {
        argv1[index] = NULL;
        arg = 2;
        index = 0;
      }
      continue;
    }
    else {
      if (arg == 0) {
        cmd = chr;
      }
      else if (arg == 1) {
        argv1[index++] = chr;
      }
      else if (arg == 2) {
        argv2[index++] = chr;
      }
    }
  }

#ifdef USE_BASE
  // 2) PID loop
  if (millis() > nextPID) {
    updatePID();
    nextPID += PID_INTERVAL;
  }
      // 3) Auto‐stop for drive motors
  if ((millis() - lastMotorCommand) > AUTO_STOP_INTERVAL) {
    setMotorSpeeds(0, 0);
    left_speed  = 0;
    right_speed = 0;
    moving = 0;
  }

  // 4) Auto‐stop for grabber (if no grabber command recently)
  if ((millis() - lastGrabberCommand) > AUTO_STOP_INTERVAL) {
    setGrabberSpeed(0);
    collector_activated = false;
    currentlyReversing  = false;
    reverseUntil        = 0;
    grabber = false;
    stuck = false;
    set_time = false;
  }

  // 5) Auto‐stop for servos
  if ((millis() - lastServoCommand) > AUTO_STOP_INTERVAL) {
    setServo(0, 0);
    setServo(1, 0);
  }
  battery_level();
  //a_x = a.acceleration.x;
  //a_y = a.acceleration.y;
  //a_z = a.acceleration.z;
  //g_x = g.gyro.x;
  //g_y = g.gyro.y;
  //g_z = g.gyro.z;

  if (millis() - checkEncoder > 100){
    if(grabber != true && collector_activated == true){
      //Serial.print("CHECKING");
      grabber = true;
    }
  }

  bool nowA = digitalRead(encoderPinA);
  if (nowA != lastA) {
    switchCount++;
    lastA = nowA;
  }
  // report every second
  if (millis() - lastReport >= 1000) {
    //Serial.print("Edges in last 1 s: ");
    //Serial.println(switchCount);
    if (switchCount < 200 && grabber) {
      if(stuck != true){
        //Serial.print("STUCK");
        stuck = true;
        stuckTime = millis();
      }
    }
    switchCount = 0;
    lastReport += 1000;
  }

#endif
#ifdef USE_SERVOS
  for (int i = 0; i < N_SERVOS; i++) {
    servos[i].doSweep();
  }

  
#endif
}

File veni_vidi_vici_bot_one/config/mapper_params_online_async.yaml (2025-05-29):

slam_toolbox:
  ros__parameters:

    # Plugin params
    solver_plugin: solver_plugins::CeresSolver
    ceres_linear_solver: SPARSE_NORMAL_CHOLESKY
    ceres_preconditioner: SCHUR_JACOBI
    ceres_trust_strategy: LEVENBERG_MARQUARDT
    ceres_dogleg_type: TRADITIONAL_DOGLEG
    ceres_loss_function: None

    # ROS Parameters
    odom_frame: odom
    map_frame: map
    base_frame: base_footprint
    scan_topic: /scan
    mode: mapping  #localization mapping 

    # if you'd like to immediately start continuing a map at a given pose
    # or at the dock, but they are mutually exclusive, if pose is given
    # will use pose
    ###map_file_name: /home/marko/dev_sim_ws/my_map_serial
    # map_start_pose: [0.0, 0.0, 0.0]
    ###map_start_at_dock: true

    debug_logging: false
    throttle_scans: 1
    transform_publish_period: 0.02 #if 0 never publishes odometry
    map_update_interval: 5.0
    resolution: 0.05
    max_laser_range: 20.0 #for rastering images
    minimum_time_interval: 0.5
    transform_timeout: 0.2
    tf_buffer_duration: 30.
    stack_size_to_use: 40000000 #// program needs a larger stack size to serialize large maps
    enable_interactive_mode: true

    # General Parameters
    use_scan_matching: true
    use_scan_barycenter: true
    minimum_travel_distance: 0.5
    minimum_travel_heading: 0.5
    scan_buffer_size: 10
    scan_buffer_maximum_scan_distance: 10.0
    link_match_minimum_response_fine: 0.1  
    link_scan_maximum_distance: 1.5
    loop_search_maximum_distance: 3.0
    do_loop_closing: true 
    loop_match_minimum_chain_size: 10           
    loop_match_maximum_variance_coarse: 3.0  
    loop_match_minimum_response_coarse: 0.35    
    loop_match_minimum_response_fine: 0.45

    # Correlation Parameters - Correlation Parameters
    correlation_search_space_dimension: 0.5
    correlation_search_space_resolution: 0.01
    correlation_search_space_smear_deviation: 0.1 

    # Correlation Parameters - Loop Closure Parameters
    loop_search_space_dimension: 8.0
    loop_search_space_resolution: 0.05
    loop_search_space_smear_deviation: 0.03

    # Scan Matcher Parameters
    distance_variance_penalty: 0.5      
    angle_variance_penalty: 1.0    

    fine_search_angle_offset: 0.00349     
    coarse_search_angle_offset: 0.349   
    coarse_angle_resolution: 0.0349        
    minimum_angle_penalty: 0.9
    minimum_distance_penalty: 0.5
    use_response_expansion: true

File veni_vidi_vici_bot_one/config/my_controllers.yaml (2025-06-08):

controller_manager:
  ros__parameters:
    update_rate: 30
    diff_cont:
      type: diff_drive_controller/DiffDriveController
    joint_broad:
      type: joint_state_broadcaster/JointStateBroadcaster
    door_servo:
      type: velocity_controllers/JointGroupVelocityController
    ramp_servo:
      type: velocity_controllers/JointGroupVelocityController
    collector_servo:
      type: velocity_controllers/JointGroupVelocityController

diff_cont:
  ros__parameters:
    publish_rate: 50.0
    base_frame_id: base_link
    left_wheel_names: ['left_wheel_joint']
    right_wheel_names: ['right_wheel_joint']
    wheel_separation: 0.4
    wheel_radius: 0.06
    use_stamped_vel: false

door_servo:
  ros__parameters:
    joints:
      - door_joint

ramp_servo:
  ros__parameters:
    joints:
      - ramp_joint

collector_servo:
  ros__parameters:
    joints:
      - collector_joint

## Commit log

2025-05-02 locomotion motors work with command
2025-05-03 added battery
2025-05-03 fixed files
    [robot_controller_example.yaml]
2025-05-03 added submodule
    [robot_controller_example.yaml]
2025-05-03 added right files
    [diffbot.materials.xacro, diffbot.ros2_control.xacro, diffbot.urdf.xacro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]
2025-05-04 updated the arduino comms
2025-05-08 need to change the motor direction
2025-05-08 updated motor min PWM
2025-05-08 reconfigured wheels
2025-05-08 calibrated again
2025-05-08 updated driver for test
    [diffbot_controllers.yaml]
2025-05-25 added servos
2025-05-26 added the lidar repo
2025-05-29 attempting slam
    [button_pose.csv, camera.xacro, inertial_macros.xacro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]
2025-05-29 modified usbport
    [ros2_control.xacro]
2025-05-30 updated baud rate
    [ros2_control.xacro]
2025-05-30 modified urdf
    [robot_core.xacro]
2025-05-30 testing lidar
2025-05-30 corrected values
    [my_controllers.yaml]
2025-05-30 added lidar to launch file
2025-05-31 added lidar files
2025-06-01 modified lidar values
2025-06-01 added the description
    [camera.xacro, inertial_macros.xacro, lidar.xacro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]
2025-06-01 added description
    [camera.xacro, inertial_macros.xacro, lidar.xacro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]
2025-06-01 added right port + baud
    [ros2_control.xacro]
2025-06-02 removed lidar from launch
2025-06-02 tweaked controller
    [diffbot_controllers.yaml]
2025-06-04 modified camera module
    [initial_pose.csv]
2025-06-04 hardware interface complete
    [my_controllers.yaml, robot_core.xacro, ros2_control.xacro]
2025-06-04 rviz2 no works
    [my_controllers.yaml]
2025-06-05 Lidar works sometimes :(
    [my_controllers.yaml]
2025-06-05 fixed some features
    [button_pose.csv, mission1_points_pose.csv]
2025-06-06 fixed encoders
2025-06-08 touched button
    [S_pose.csv, button_pose.csv, lidar.xacro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]
2025-06-08 saved description
    [camera.xacro, lidar.xacro]
2025-06-08 can press button pretty well
    [button_pose.csv, mission1_points_pose.csv]
2025-06-09 somewhat autonomous
    [button_pose.csv, mission1_points_pose.csv, mission2_points_pose.csv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]
2025-06-11 final code
    [button_pose.csv, list_of_timeouts.csv, mission1_points_pose.csv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]
2025-06-13 competition run
    [list_of_timeouts.csv, mission12_points_pose.csv, mission1_points_pose.csv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]
